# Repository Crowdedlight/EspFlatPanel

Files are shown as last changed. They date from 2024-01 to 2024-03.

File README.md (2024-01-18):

# EspFlatPanel
Code for ESP32-S3 and ASCOM Alpaca driver for wireless Flat Panel running DotStar LED strip.

Test of it can be seen here: https://youtu.be/fPaTHsD9jYk

**Libs required:**  
ArduinoJson 7.0  
FastLED 3.6.0  

**They should be installed automatically through platformio when loading this workspace**

Tested and verified with ASCOM ConformU to conforming to the Ascom Alpaca Standard:  
```
20:53:32.934 ASCOM Universal Device Conformance Checker Version 2.2.0.23978, Build time: ons 17 januar 2024 10:30:52
20:53:32.934
20:53:32.935 Operating system is Microsoft Windows 10.0.19045 64bit, Application is 64bit.
20:53:32.936
20:53:32.937 Alpaca device: Esp Flat Panel (192.168.11.19:4567 CoverCalibrator/0)
20:53:32.938
20:53:32.938 CreateDevice                        INFO     Creating Alpaca device: IP address: 192.168.11.19, IP Port: 4567, Alpaca device number: 0
20:53:32.939 CreateDevice                        INFO     Alpaca device created OK
20:53:32.940 CreateDevice                        INFO     Successfully created driver
20:53:33.947 CreateDevice                        OK       Driver instance created successfully
20:53:33.948
20:53:33.949 Pre-connect checks
20:53:33.949
20:53:33.950 Connect to device
20:53:34.209 Connected                           OK       Connected to device successfully using Connected = True
20:53:34.211
20:53:34.211 Common Driver Methods
20:53:34.212 InterfaceVersion                    OK       1
20:53:34.262 Connected                           OK       True
20:53:34.318 Description                         OK       ESP32 Alpaca controlled flat-panel for use with DotStar LED strip and a homemade flatpanel
20:53:34.362 DriverInfo                          OK       Driver is firmware made by Crowdedlight for ESP32-S3: https://github.com/Crowdedlight/EspFlatPanel
20:53:34.407 DriverVersion                       OK       v1.0.0
20:53:34.468 Name                                OK       Esp Flat Panel
20:53:34.468
20:53:34.469 Action                              INFO     Conform cannot test the Action method
20:53:34.505 SupportedActions                    OK       Driver returned an empty action list
20:53:34.506
20:53:34.507 DeviceState                         INFO     DeviceState tests omitted - DeviceState is not available in this interface version.
20:53:34.507
20:53:34.508 Properties
20:53:34.559 CalibratorState                     OK       Off
20:53:34.608 CoverState                          OK       NotPresent
20:53:34.683 MaxBrightness                       OK       255
20:53:34.794 Brightness                          OK       255
20:53:34.794
20:53:34.796 Methods
20:53:34.853 OpenCover                           OK       CoverStatus is 'NotPresent' and a NotImplementedException error was generated as expected
20:53:34.931 CloseCover                          OK       CoverStatus is 'NotPresent' and a NotImplementedException error was generated as expected
20:53:34.973 HaltCover                           OK       CoverStatus is 'NotPresent' and a NotImplementedException error was generated as expected
20:53:35.016 CalibratorOn                        OK       CalibratorOn with brightness -1 threw an InvalidValueException as expected
20:53:35.153 CalibratorOn                        OK       CalibratorOn with brightness 0 was successful. The synchronous operation took 0,1 seconds
20:53:35.198 CalibratorOn                        OK       The Brightness property does return the value that was set
20:53:35.298 CalibratorOn                        OK       CalibratorOn with brightness 63 was successful. The synchronous operation took 0,1 seconds
20:53:35.374 CalibratorOn                        OK       The Brightness property does return the value that was set
20:53:35.504 CalibratorOn                        OK       CalibratorOn with brightness 127 was successful. The synchronous operation took 0,1 seconds
20:53:35.551 CalibratorOn                        OK       The Brightness property does return the value that was set
20:53:35.676 CalibratorOn                        OK       CalibratorOn with brightness 191 was successful. The synchronous operation took 0,1 seconds
20:53:35.729 CalibratorOn                        OK       The Brightness property does return the value that was set
20:53:35.855 CalibratorOn                        OK       CalibratorOn with brightness 255 was successful. The synchronous operation took 0,1 seconds
20:53:35.909 CalibratorOn                        OK       The Brightness property does return the value that was set
20:53:35.949 CalibratorOn                        OK       CalibratorOn with brightness 256 threw an InvalidValueException as expected
20:53:36.076 CalibratorOff                       OK       CalibratorOff was successful. The synchronous action took 0,1 seconds
20:53:36.106 CalibratorOff                       OK       Brightness is set to zero when the calibrator is turned off
20:53:36.107
20:53:36.108 Disconnect from device
20:53:36.178 Connected                           OK       False
20:53:36.180
20:53:36.180 Conformance test has finished
20:53:36.181
20:53:36.182 No errors, warnings or issues found: your driver passes ASCOM validation!!
```

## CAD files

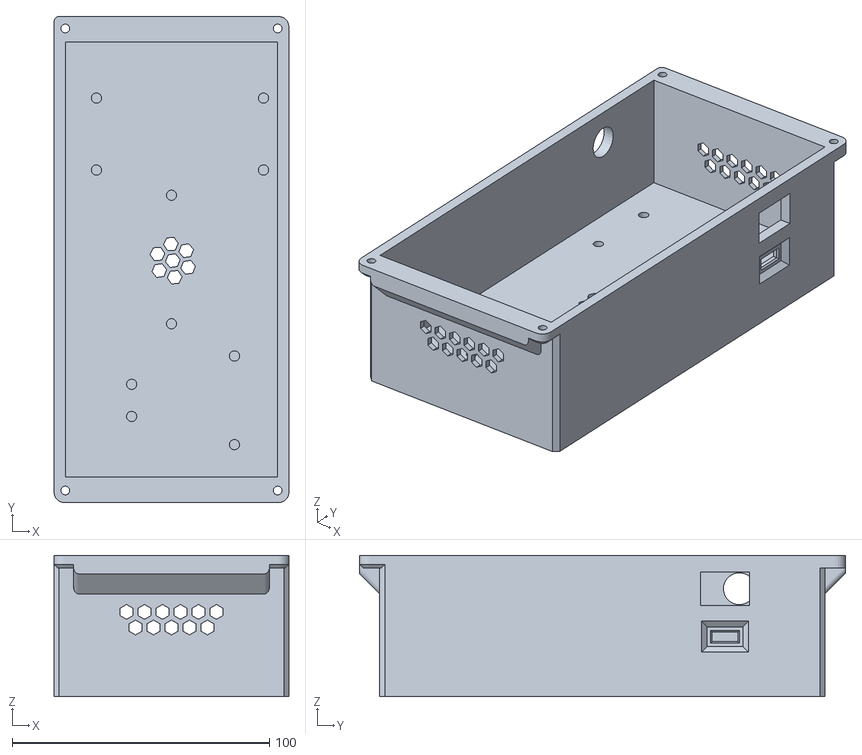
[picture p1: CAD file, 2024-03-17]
3d_print/inventor_Flat_Panel/electronics-mount.stl
91.4 x 189.1 x 55.0

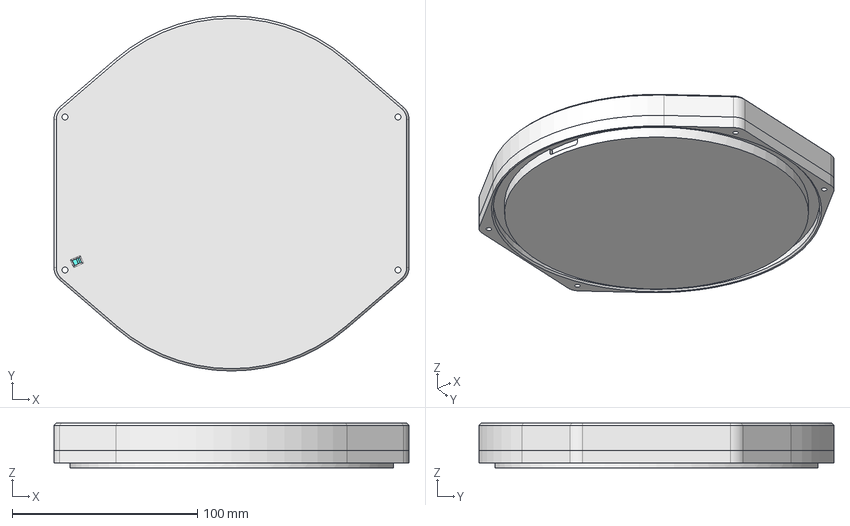
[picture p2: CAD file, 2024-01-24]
3d_print/original_parameterized/FreeCAD_Model-Flat_Panel.step
191.6 x 191.6 x 24.1 mm
Front
Spacer
Cover

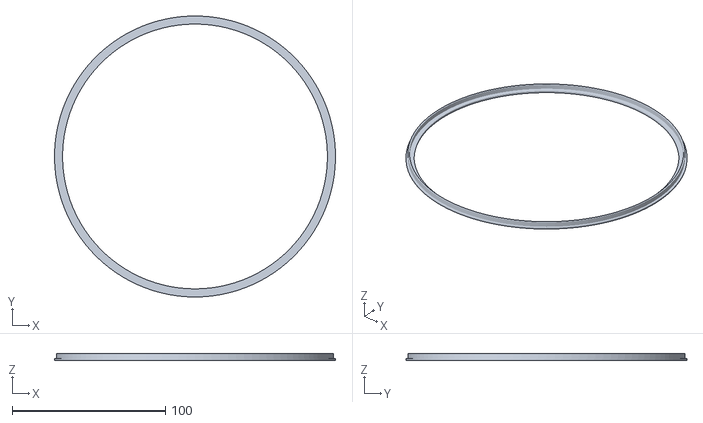
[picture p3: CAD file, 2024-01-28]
3d_print/stl/Spacer_179mm_internal_diffuser.stl
183.6 x 183.6 x 4.25

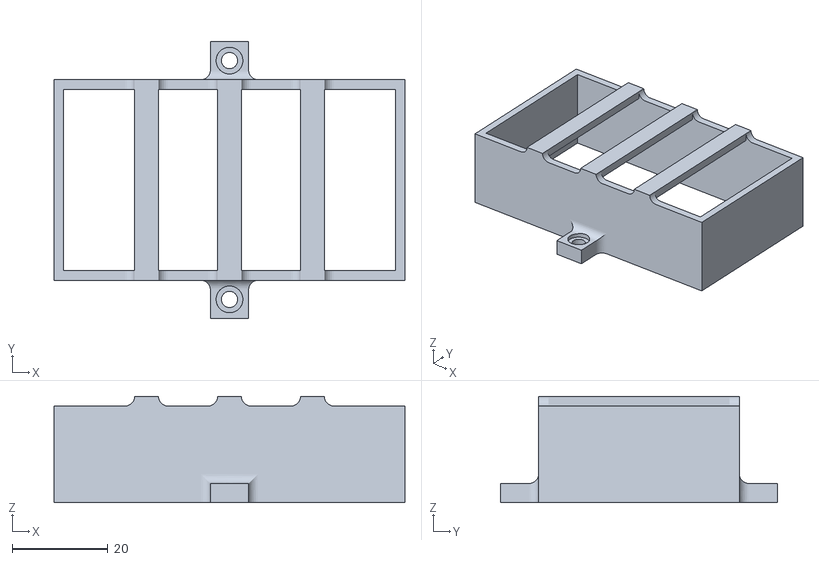
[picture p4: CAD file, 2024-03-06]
3d_print/inventor_Flat_Panel/battery_holder.stl
73.5 x 58.0 x 22.2

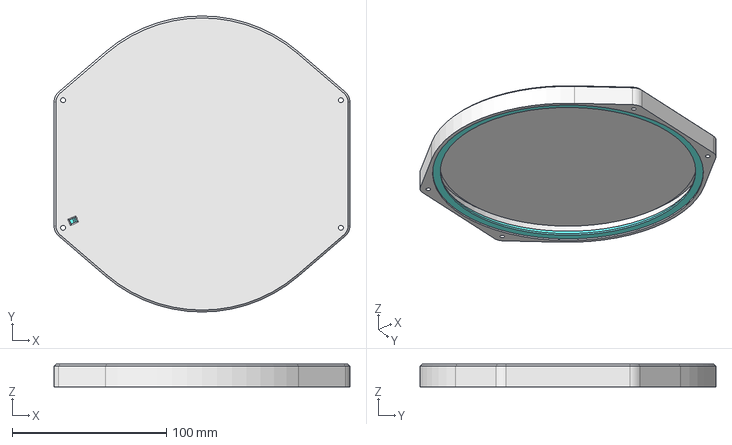
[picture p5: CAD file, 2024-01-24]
3d_print/original_parameterized/FreeCAD_Model.FCStd
191.6 x 191.6 x 14.7 mm
Spacer

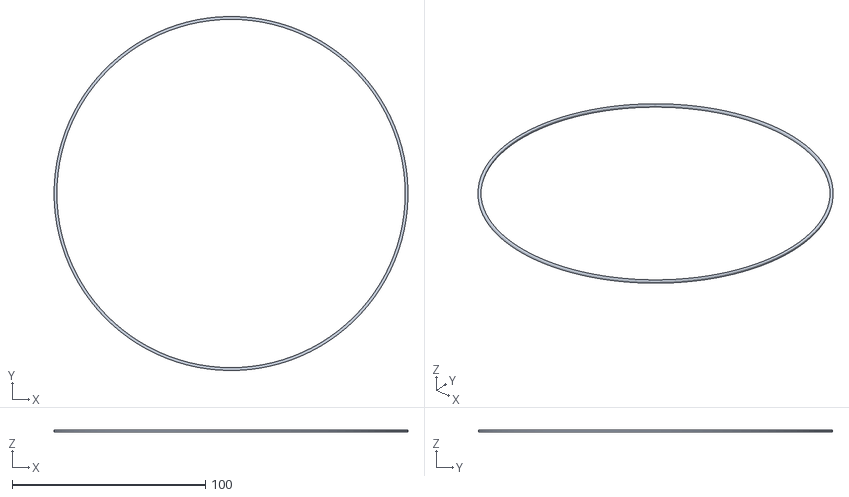
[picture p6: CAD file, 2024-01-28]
3d_print/stl/external_diffuser_spacer.stl
183.3 x 183.3 x 1.15

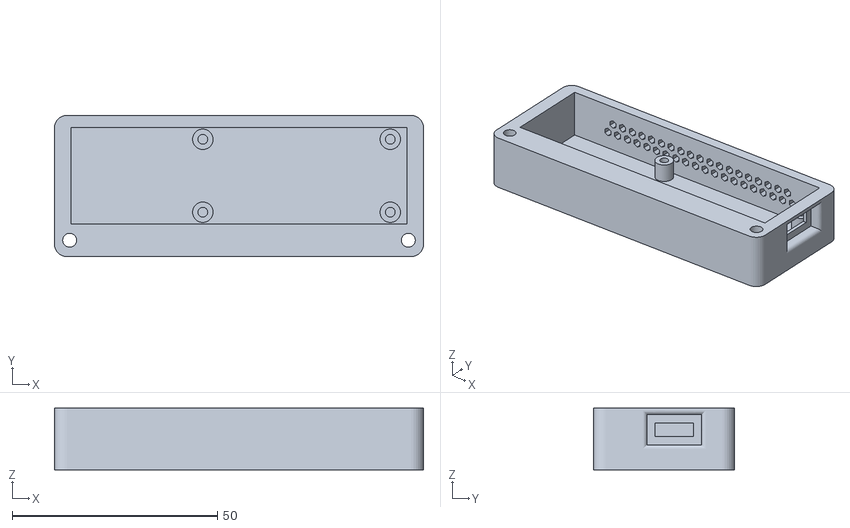
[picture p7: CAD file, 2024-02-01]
3d_print/inventor_Flat_Panel/esp32_mount.stl
90.0 x 34.5 x 15.0

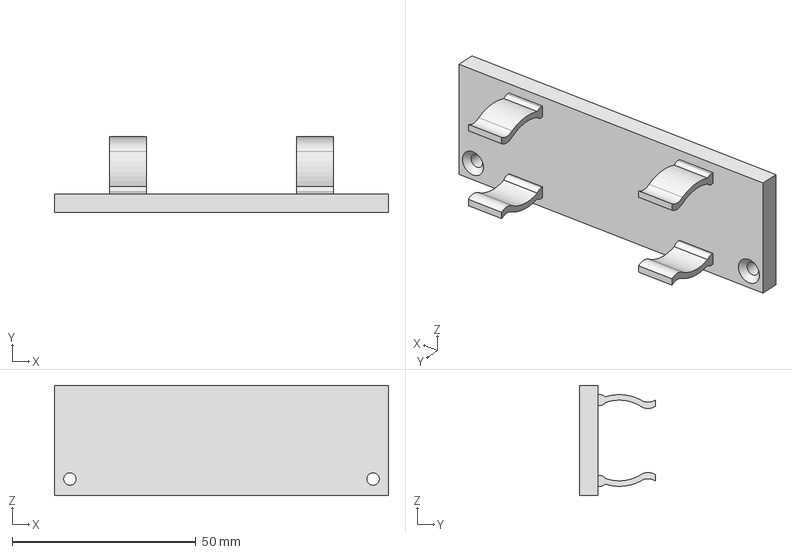
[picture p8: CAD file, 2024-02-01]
3d_print/inventor_Flat_Panel/powerbank_mount_v1.stp
91.0 x 20.6 x 30.0 mm

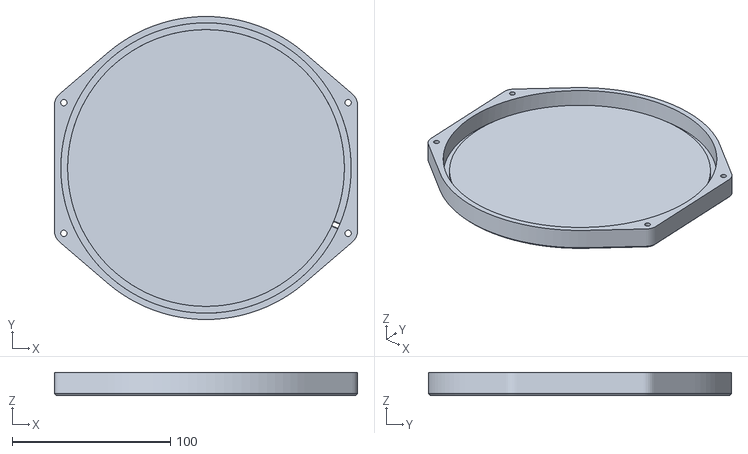
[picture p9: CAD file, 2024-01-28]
3d_print/stl/Body.stl
191.6 x 191.6 x 14.6

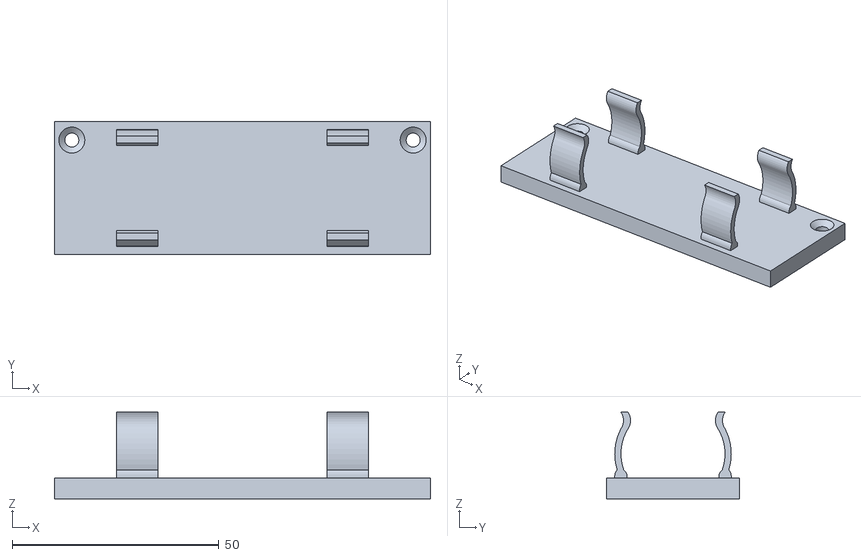
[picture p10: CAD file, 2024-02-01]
3d_print/inventor_Flat_Panel/powerbank_mount.stl
91.0 x 32.2 x 20.9

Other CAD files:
3d_print/stl/Spacer_177mm_internal_diffuser.stl
3d_print/stl/Spacer.stl
3d_print/inventor_Flat_Panel/Body.ipt
3d_print/inventor_Flat_Panel/Cover.ipt
3d_print/inventor_Flat_Panel/FreeCAD_Model-Flat_Panel.iam
3d_print/inventor_Flat_Panel/Front.ipt
3d_print/inventor_Flat_Panel/OldVersions/Body.0009.ipt
3d_print/inventor_Flat_Panel/OldVersions/FreeCAD_Model-Flat_Panel.0005.iam
3d_print/inventor_Flat_Panel/OldVersions/Spacer.0005.ipt
3d_print/inventor_Flat_Panel/OldVersions/battery_holder.0003.ipt
3d_print/inventor_Flat_Panel/OldVersions/electronics-mount.0018.ipt
3d_print/inventor_Flat_Panel/OldVersions/electronics_assembly.0001.iam
3d_print/inventor_Flat_Panel/OldVersions/esp32_mount.0023.ipt
3d_print/inventor_Flat_Panel/OldVersions/external_diffuser_spacer.0003.ipt
3d_print/inventor_Flat_Panel/OldVersions/powerbank_mount.0003.ipt
3d_print/inventor_Flat_Panel/Spacer.ipt
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

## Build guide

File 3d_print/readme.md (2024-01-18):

# 3D prints
The freecad models were made by https://github.com/jlecomte And is available here: https://github.com/jlecomte/ascom-wireless-flat-panel/tree/master/3D_Files under MIT license. I only included them here for my own organisational purpose. I urge you to go check out his project! 

It was his project that inspired me to make my own ESP32 driver without needing a custom ASCOM driver. Go check out his repo, some very nice information there especially on the mechanical side of building the flat panel.

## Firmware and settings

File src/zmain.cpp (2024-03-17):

// Alpaca Ascom control of flat-panel running on FastLED compatible LED strips. 

#include <Arduino.h>

#include "WiFi.h"
#include "WebServer.h"
#include "AsyncUDP.h"
#include "config.h"
#include "ArduinoJson.h"
#include "FastLED.h"

// enable debugging values
const bool DEBUG = false;

const char *ssid = _SSID;           // your network SSID (name)
const char *password = _PASSWORD;   // your network password (use for WPA, or use as key for WEP)

unsigned const int discoveryPort = 32227;  //The Alpaca Discovery port
unsigned const int alpacaPort = 4567;  //The (fake) port that the Alpaca API would be available on
const char *uuid = "8de70ae6-ce7b-4741-ae69-1294a316e906";

// Device Specific information
String deviceNameNoSpace = "EspFlatPanel";
String Manufacturer = "Crowdedlight";
String Version = "v1.0.0";
String ManufacturerLocation = "The Milky Way";
String DeviceName = "Esp Flat Panel";
String DeviceType = "CoverCalibrator";
String DeviceDescription = "ESP32 Alpaca controlled flat-panel for use with DotStar LED strip and a homemade flatpanel";
String DriverInfo = "Driver is firmware made by Crowdedlight for ESP32-S3: https://github.com/Crowdedlight/EspFlatPanel";

AsyncUDP udp_discovery;
WebServer server(alpacaPort);

// LED DEBUGGING
#define BLINK_INTERVAL 1000 //every 1000 ms
unsigned long last_blink;
int led_state;

// STATES
enum States: int {
  NOT_PRESENT = 0, 
  OFF = 1, 
  NOT_READY = 2, 
  READY = 3, 
  UNKNOWN = 4, 
  ERROR = 5
};

// LED CONTROL - FASTLED
#define DATA_PIN  23 
#define CLOCK_PIN 18 

#define NUM_LEDS    59
#define LED_TYPE    APA102
#define COLOR_ORDER GRB
CRGB leds[NUM_LEDS];
#define UPDATES_PER_SECOND 100

// hardcode colour to neutral white
// RGB(252, 250, 246), #FCFAF6 
CRGB NEUTRAL_WHITE = CRGB( 252, 250, 246);

// default is that the LEDs are off, waiting for commands to turn on
unsigned int MaxBrightness = 255;
unsigned int CalibratorState = States::OFF;
bool alpacaConnected = false;

/*
******* REMEMBER TO EDIT CONFIG.H FOR YOUR CONFIGURATION *******
*/

// API callbacks
void handleNotFound();
void handleNotImplemented();
void handleTransactionAndClientIds(JsonDocument &doc);
// Common 
void connectedPutRequest();
void connectedGetRequest();
void SimpleDescriptionRequest();
// Management and Protocol specific
void discoveryRequest(AsyncUDPPacket &packet);
void ConfiguredDevicesRequest();
void ApiVersionsRequest();
void DescriptionRequest();
void DriverInfoRequest();
void DriverVersionRequest();
void InterfaceVersionRequest();
void nameRequest();
void supportedActionsRequest();
// Type specific
void BrightnessRequest();
void CalibratorStateRequest();
void CoverStateRequest();
void MaxBrightnessRequest();
void CalibratorOffRequest();
void CalibratorOnRequest();

// Control functions
void TurnOn(int brightness);
void TurnOff();

void setup ()
{
  // setup serial
  Serial.begin(115200);

  // setup LED Pin
  pinMode(LED_BUILTIN, OUTPUT);
  last_blink = millis();
  led_state = HIGH;
  digitalWrite(LED_BUILTIN, led_state);

  // safety startup delay
  delay(2000);

  // setup LEDs
  // FastLED.addLeds<APA102, DATA_PIN, CLOCK_PIN, RGB>(leds, NUM_LEDS).setCorrection(TypicalLEDStrip);  // BGR ordering is typical
  FastLED.addLeds<APA102, DATA_PIN, CLOCK_PIN, RGB, DATA_RATE_MHZ(5)>(leds, NUM_LEDS).setCorrection(TypicalLEDStrip); 

  // clear all data and push to LEDs. So we start with them turned off. 
  FastLED.clear(true);
  FastLED.setBrightness(0);

  // setup WIFI
  WiFi.mode(WIFI_STA);
  WiFi.begin(ssid, password);
  if (WiFi.waitForConnectResult() != WL_CONNECTED)
  {
      Serial.println("WiFi Failed");
      while (1)
      {
          delay(1000);
      }
  }
  Serial.print("Connect with IP Address: ");
  Serial.println(WiFi.localIP());

  // SETUP UDP REQUESTS - Discovery
  if (udp_discovery.listen(discoveryPort))
  {
      Serial.println("Listening for discovery requests...");
      udp_discovery.onPacket(discoveryRequest);
      
  } else 
      Serial.println("failed to add listener for alpaca discovery request");

  // HTTP Server for the command and management api
  server.on("/management/v1/configureddevices", HTTP_GET, ConfiguredDevicesRequest);
  server.on("/management/apiversions", HTTP_GET, ApiVersionsRequest);
  server.on("/management/v1/description", HTTP_GET, DescriptionRequest);
  // common alpaca methods shared across all device types
  server.on("/api/v1/covercalibrator/0/connected", HTTP_PUT, connectedPutRequest);
  server.on("/api/v1/covercalibrator/0/connected", HTTP_GET, connectedGetRequest);
  server.on("/api/v1/covercalibrator/0/description", HTTP_GET, SimpleDescriptionRequest);
  server.on("/api/v1/covercalibrator/0/driverinfo", HTTP_GET, DriverInfoRequest);
  server.on("/api/v1/covercalibrator/0/driverversion", HTTP_GET, DriverVersionRequest);
  server.on("/api/v1/covercalibrator/0/interfaceversion", HTTP_GET, InterfaceVersionRequest);
  server.on("/api/v1/covercalibrator/0/name", HTTP_GET, nameRequest);
  server.on("/api/v1/covercalibrator/0/supportedactions", HTTP_GET, supportedActionsRequest);

  // not implemented apis for cover
  server.on("/api/v1/covercalibrator/0/opencover", HTTP_PUT, handleNotImplemented);
  server.on("/api/v1/covercalibrator/0/closecover", HTTP_PUT, handleNotImplemented);
  server.on("/api/v1/covercalibrator/0/haltcover", HTTP_PUT, handleNotImplemented);

  // Command API For CoverCalibrator
  // We can hardcode the device-number, as we only support 1 device for now. 
  // Only implementing the brightness, states, and max brightness api calls. Everything else will go to "nothandled" and return appropiate error of not implemented.
  server.on("/api/v1/covercalibrator/0/brightness", HTTP_GET, BrightnessRequest);
  server.on("/api/v1/covercalibrator/0/calibratorstate", HTTP_GET, CalibratorStateRequest);
  server.on("/api/v1/covercalibrator/0/coverstate", HTTP_GET, CoverStateRequest); // just returns 200 "NotPresent	int: 0	This device does not have a cover that can be closed independently "
  server.on("/api/v1/covercalibrator/0/maxbrightness", HTTP_GET, MaxBrightnessRequest);
  // put requests aka. Actual control of the calibrator
  server.on("/api/v1/covercalibrator/0/calibratoroff", HTTP_PUT, CalibratorOffRequest);
  server.on("/api/v1/covercalibrator/0/calibratoron", HTTP_PUT, CalibratorOnRequest);

  // TODO implement the last API calls, including the LED state specific stuff. Need to have an LED state to return

  server.onNotFound(handleNotFound);
  server.begin();
  Serial.println("HTTP server started");

}  // end of setup

void loop ()
{
  // get time
  unsigned long curr_millis = millis();

  // blink led to show we are still running
  if ((curr_millis - last_blink) > BLINK_INTERVAL) {
    // flip led state
    led_state = led_state ? LOW : HIGH;
    digitalWrite(LED_BUILTIN, led_state);
    last_blink = curr_millis;
  }  

  server.handleClient();
  delay(2);//allow the cpu to switch to other tasks
}  // end of loop


void discoveryRequest(AsyncUDPPacket &packet) {
  // debug message
  if (DEBUG) {
    Serial.print("Received UDP Packet of Type: ");
    Serial.print(packet.isBroadcast() ? "Broadcast" : packet.isMulticast() ? "Multicast" : "Unicast");
    Serial.print(", From: ");
    Serial.print(packet.remoteIP());
    Serial.print(":");
    Serial.print(packet.remotePort());
    Serial.print(", To: ");
    Serial.print(packet.localIP());
    Serial.print(":");
    Serial.print(packet.localPort());
    Serial.print(", Length: ");
    Serial.print(packet.length());
    Serial.print(", Data: ");
    Serial.write(packet.data(), packet.length());
    Serial.println();
  }

  // No undersized packets allowed
  if (packet.length() < 16)
      return;

  //Compare packet to Alpaca Discovery string
  if (strncmp("alpacadiscovery1", (char *)packet.data(), 16) != 0)
      return;

  // send a reply, to the IP address with port for webserver
  packet.printf("{\"AlpacaPort\": %d}", alpacaPort);
}

void handleNotFound() {
  String message = "File Not Found\n\n";
  message += "URI: ";
  message += server.uri();
  message += "\nMethod: ";
  message += (server.method() == HTTP_GET) ? "GET" : "POST";
  message += "\nArguments: ";
  message += server.args();
  message += "\n";
  for (uint8_t i = 0; i < server.args(); i++) {
    message += " " + server.argName(i) + ": " + server.arg(i) + "\n";
  }
  server.send(403, "text/plain", message);

  Serial.println(message); // debug to see what they ask of us that isn't implemented!
}

void handleTransactionAndClientIds(JsonDocument &doc) {
  if (server.hasArg("ClientID")) {
    doc["ClientID"] = server.arg("ClientID").toInt();
  }  
  if (server.hasArg("ClientTransactionID")) {
    doc["ClientTransactionID"] = server.arg("ClientTransactionID").toInt();
  }
}

void handleNotImplemented() {
  JsonDocument doc;
  // handle arguments/parameters of: ClientID & ClientTransactionID
  handleTransactionAndClientIds(doc);
  JsonObject root = doc.to<JsonObject>();
  doc["ErrorNumber"] = 0x400; // NOT IMPLEMENTED ERROR CODE
  doc["ErrorMessage"] = "This device has no cover connected";

  String output;
  serializeJson(doc, output);

  server.send(200, "application/json", output);
}

void ApiVersionsRequest() {
  Serial.println("Received 'ApiVersions' request");
  Serial.flush();

  JsonDocument doc;

  // handle arguments/parameters of: ClientID & ClientTransactionID
  handleTransactionAndClientIds(doc);

  JsonArray value = doc["value"].to<JsonArray>();
  value.add(1);

  String output;
  serializeJson(doc, output);

  server.sendHeader("Cache-Control", "no-cache");
  server.send(200, "application/json", output);
}

void connectedGetRequest() {
  Serial.println("Received 'Connected' Get request");
  Serial.flush();

  JsonDocument doc;

  // handle arguments/parameters of: ClientID & ClientTransactionID
  handleTransactionAndClientIds(doc);

  JsonObject root = doc.to<JsonObject>();
  doc["Value"] = alpacaConnected;

  String output;
  serializeJson(doc, output);

  if (DEBUG) {
    serializeJson(doc, Serial);
  }

  server.send(200, "application/json", output);
}

void connectedPutRequest() {
  Serial.println("Received 'Connected' Put request");
  Serial.flush();

  JsonDocument doc;

  // handle arguments/parameters of: ClientID & ClientTransactionID
  handleTransactionAndClientIds(doc);

  // check argument, if brightness is within range and exist, we turn on, otherwise we throw error
  if (!server.hasArg("Connected")) {
    server.send(400, "text/plain", "Missing Connected value");
    return;
  }

  // get bool from request
  bool newStatus = false;
  String reqStatus = server.arg("Connected");

  if (reqStatus.equalsIgnoreCase("true")) {
    newStatus = true;
  }

  // set connected state
  alpacaConnected = newStatus;

  doc["ErrorNumber"] = 0;
  doc["ErrorMessage"] = "";

  String output;
  serializeJson(doc, output);

  if (DEBUG) {
    serializeJson(doc, Serial);
  }

  server.sendHeader("Cache-Control", "no-cache");
  server.send(200, "application/json", output);
}

void SimpleDescriptionRequest() {
  Serial.println("Received 'simple description' request");
  Serial.flush();

  JsonDocument doc;

  // handle arguments/parameters of: ClientID & ClientTransactionID
  handleTransactionAndClientIds(doc);

  JsonObject root = doc.to<JsonObject>();
  doc["Value"] = DeviceDescription;

  String output;
  serializeJson(doc, output);

  if (DEBUG) {
    serializeJson(doc, Serial);
  }

  server.send(200, "application/json", output);
}

void DriverInfoRequest() {
  Serial.println("Received 'driverinfo' request");
  Serial.flush();

  JsonDocument doc;

  // handle arguments/parameters of: ClientID & ClientTransactionID
  handleTransactionAndClientIds(doc);

  JsonObject root = doc.to<JsonObject>();
  doc["Value"] = DriverInfo;

  String output;
  serializeJson(doc, output);

  if (DEBUG) {
    serializeJson(doc, Serial);
  }

  server.send(200, "application/json", output);
}

void DriverVersionRequest() {
  Serial.println("Received 'driverversion' request");
  Serial.flush();

  JsonDocument doc;

  // handle arguments/parameters of: ClientID & ClientTransactionID
  handleTransactionAndClientIds(doc);

  JsonObject root = doc.to<JsonObject>();
  doc["Value"] = Version;

  String output;
  serializeJson(doc, output);

  if (DEBUG) {
    serializeJson(doc, Serial);
  }

  server.send(200, "application/json", output);
}

void InterfaceVersionRequest() {
  Serial.println("Received 'interfaceversion' request");
  Serial.flush();

  JsonDocument doc;

  // handle arguments/parameters of: ClientID & ClientTransactionID
  handleTransactionAndClientIds(doc);

  JsonObject root = doc.to<JsonObject>();
  doc["Value"] = 1;

  String output;
  serializeJson(doc, output);

  if (DEBUG) {
    serializeJson(doc, Serial);
  }

  server.send(200, "application/json", output);
}

void nameRequest() {
  Serial.println("Received 'name' request");
  Serial.flush();

  JsonDocument doc;

  // handle arguments/parameters of: ClientID & ClientTransactionID
  handleTransactionAndClientIds(doc);

  JsonObject root = doc.to<JsonObject>();
  doc["Value"] = DeviceName;

  String output;
  serializeJson(doc, output);

  if (DEBUG) {
    serializeJson(doc, Serial);
  }

  server.send(200, "application/json", output);
}

void supportedActionsRequest() {
  Serial.println("Received 'supportedActions' request");
  Serial.flush();

  JsonDocument doc;

  // handle arguments/parameters of: ClientID & ClientTransactionID
  handleTransactionAndClientIds(doc);

  JsonObject root = doc.to<JsonObject>();
  JsonArray value = doc["Value"].to<JsonArray>();
  // This is to add custom actions that is otherwise not described in the alpaca protocol as I understand it. So could potentially add "SetColour" or similar to it. Sending no custom entries for now. 
  //value.add("");

  String output;
  serializeJson(doc, output);

  if (DEBUG) {
    serializeJson(doc, Serial);
  }

  server.send(200, "application/json", output);
}

void DescriptionRequest() {
  Serial.println("Received 'Description' request");
  Serial.flush();

  JsonDocument doc;

  // handle arguments/parameters of: ClientID & ClientTransactionID
  handleTransactionAndClientIds(doc);

  JsonObject root = doc.to<JsonObject>();
  JsonObject value = doc["Value"].to<JsonObject>();
  value["ServerName"] = deviceNameNoSpace;
  value["Manufacturer"] = Manufacturer;
  value["ManufacturerVersion"] = Version;
  value["Location"] = ManufacturerLocation;

  String output;
  serializeJson(doc, output);

  if (DEBUG) {
    serializeJson(doc, Serial);
  }

  server.send(200, "application/json", output);
}

void ConfiguredDevicesRequest() {
  Serial.println("Received 'ConfiguredDevices' request");
  Serial.flush();

  JsonDocument doc;

  // handle arguments/parameters of: ClientID & ClientTransactionID
  handleTransactionAndClientIds(doc);

  JsonObject root = doc.to<JsonObject>();
  JsonArray value = doc["Value"].to<JsonArray>();
  JsonObject object = value.add<JsonObject>();
  object["DeviceName"] = DeviceName;
  object["DeviceType"] = DeviceType;
  object["DeviceNumber"] = 0;
  object["UniqueID"] = uuid;

  String output;
  serializeJson(doc, output);

  if (DEBUG) {
    serializeJson(doc, Serial);
  }

  server.sendHeader("Cache-Control", "no-cache");
  server.send(200, "application/json", output);
}

void BrightnessRequest() {
  Serial.println("Received 'Brightness' request");
  Serial.flush();

  JsonDocument doc;

  // handle arguments/parameters of: ClientID & ClientTransactionID
  handleTransactionAndClientIds(doc);

  JsonObject root = doc.to<JsonObject>();
  doc["ErrorNumber"] = 0;
  doc["ErrorMessage"] = "";
  doc["Value"] = FastLED.getBrightness();  

  String output;
  serializeJson(doc, output);

  if (DEBUG) {
    serializeJson(doc, Serial);
  }

  server.sendHeader("Cache-Control", "no-cache");
  server.send(200, "application/json", output);
}

void CalibratorStateRequest() {
  Serial.println("Received 'CalibratorState' request");
  Serial.flush();

  JsonDocument doc;

  // handle arguments/parameters of: ClientID & ClientTransactionID
  handleTransactionAndClientIds(doc);
  
  JsonObject root = doc.to<JsonObject>();
  doc["ErrorNumber"] = 0;
  doc["ErrorMessage"] = "";
  doc["Value"] = CalibratorState;  

  String output;
  serializeJson(doc, output);

  if (DEBUG) {
    serializeJson(doc, Serial);
  }

  server.sendHeader("Cache-Control", "no-cache");
  server.send(200, "application/json", output);
}

void CoverStateRequest() {
  Serial.println("Received 'CoverState' request");
  Serial.flush();

  JsonDocument doc;

  // handle arguments/parameters of: ClientID & ClientTransactionID
  handleTransactionAndClientIds(doc);

  JsonObject root = doc.to<JsonObject>();
  doc["ErrorNumber"] = 0;
  doc["ErrorMessage"] = "";
  doc["Value"] = States::NOT_PRESENT;  

  String output;
  serializeJson(doc, output);

  if (DEBUG) {
    serializeJson(doc, Serial);
  }

  server.sendHeader("Cache-Control", "no-cache");
  server.send(200, "application/json", output);
}

void MaxBrightnessRequest() {
  Serial.println("Received 'MaxBrightness' request");
  Serial.flush();

  JsonDocument doc;

  // handle arguments/parameters of: ClientID & ClientTransactionID
  handleTransactionAndClientIds(doc);

  JsonObject root = doc.to<JsonObject>();
  doc["ErrorNumber"] = 0;
  doc["ErrorMessage"] = "";
  doc["Value"] = MaxBrightness;  

  String output;
  serializeJson(doc, output);

  if (DEBUG) {
    serializeJson(doc, Serial);
  }

  server.sendHeader("Cache-Control", "no-cache");
  server.send(200, "application/json", output);
}

// ----- PUT REQUESTS -----
void CalibratorOffRequest() {
  Serial.println("Received 'CalibratorOFF' request");
  Serial.flush();

  // call function to turn LEDs off
  TurnOff();

  JsonDocument doc;

  // handle arguments/parameters of: ClientID & ClientTransactionID
  handleTransactionAndClientIds(doc);

  JsonObject root = doc.to<JsonObject>();
  doc["ErrorNumber"] = 0;
  doc["ErrorMessage"] = "";

  String output;
  serializeJson(doc, output);

  if (DEBUG) {
    serializeJson(doc, Serial);
  }

  server.sendHeader("Cache-Control", "no-cache");
  server.send(200, "application/json", output);
}

void CalibratorOnRequest() {
  Serial.println("Received 'CalibratorOn' request");
  Serial.flush();

  JsonDocument doc;

  // handle arguments/parameters of: ClientID & ClientTransactionID
  handleTransactionAndClientIds(doc);

  JsonObject root = doc.to<JsonObject>();

  int err_code = 0;
  String error_msg = "";

  // check argument, if brightness is within range and exist, we turn on, otherwise we throw error
  if (!server.hasArg("Brightness")) {
    server.send(400, "text/plain", "Missing Brightness value");
    return;
  }

  int brightness = server.arg("Brightness").toInt();

  // if operation was not true, then we set error here
  if (brightness < 0 || brightness > 255) {
    err_code = 0x401; // invalid value
    error_msg = "brightness outside range 0-255";
  } else {
    // no errors, so we comply with command
    TurnOn(brightness);
  }

  doc["ErrorNumber"] = err_code;
  doc["ErrorMessage"] = error_msg;

  String output;
  serializeJson(doc, output);

  if (DEBUG) {
    serializeJson(doc, Serial);
  }

  server.sendHeader("Cache-Control", "no-cache");
  server.send(200, "application/json", output);
}

void TurnOn(int brightness) {
  // set all LEDs to specific colour
  fill_solid(leds, NUM_LEDS, NEUTRAL_WHITE);
  FastLED.setBrightness(brightness);
  FastLED.show();
  CalibratorState = States::READY;
}

void TurnOff() {
  FastLED.clear(true);
  FastLED.setBrightness(0);
  CalibratorState = States::OFF;
}

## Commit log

2024-01-10 implemented management api for Alpaca and tested it to work. Missing LED control API
    [zmain.cpp]
2024-01-11 finished implementing alpaca control, waiting on LEDs to test control
2024-01-11 added 3d model, need to add credit from author (MIT license)
    [FreeCAD_Model.FCStd]
2024-01-17 fixed errors and bugs to pass ConformU
    [zmain.cpp]
2024-01-18 changed pins for LEDs and updated readme
2024-01-18 added readme for 3d print with credit and original author
2024-01-24 added amended 3D print that fit with the external LGP and diffuser
    [Body.0007.ipt, Body.ipt, Body.stl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]
2024-01-24 removed old versions
    [Body.0007.ipt, FreeCAD_Model-Flat_Panel.0001.iam, Spacer.0003.ipt]
2024-01-28 updated 3d models for my telescope size and external LGP and diffuser aswell as mount for ESP module
    [Body.0009.ipt, Body.ipt, Body.stl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]
2024-02-01 added powerbank mount wip
    [esp32_mount.0018.ipt, esp32_mount.0023.ipt, esp32_mount.ipt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]
2024-02-03 changes for new ESP32 board
2024-02-08 new 3D model for new version of electronics and battery
    [electronics-mount.0010.ipt, electronics-mount.ipt, electronics-mount.stl]
2024-03-06 further design for electronics and battery holder
    [battery_holder.0003.ipt, battery_holder.ipt, battery_holder.stl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]
2024-03-13 electronics mount adding hole for rocker switch and making the usb-c hole bigger and chambered
    [electronics-mount.0014.ipt, electronics-mount.0016.ipt, electronics-mount.ipt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]
2024-03-17 moved push-button slightly to not hit pcb connector and changed pin-numbers to match hardware spi
    [electronics-mount.0016.ipt, electronics-mount.0018.ipt, electronics-mount.ipt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]
